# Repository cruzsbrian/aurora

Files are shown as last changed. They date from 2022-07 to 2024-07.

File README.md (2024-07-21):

# Aurora
Aurora is an addressable LED controller with a graphical interface, audio input, and patterns programmed on an SD card.
It controls up to 8 WS2811-style LED strips in parallel.
A microphone and audio jack can be used for music visualization.
LED patterns are programmed in Lua and can be modified without rebooting by replacing the SD card.

[Interactive PCB BOM viewer](https://htmlpreview.github.io/?https://github.com/cruzsbrian/aurora/blob/main/aurora_hw/bom/ibom.html)

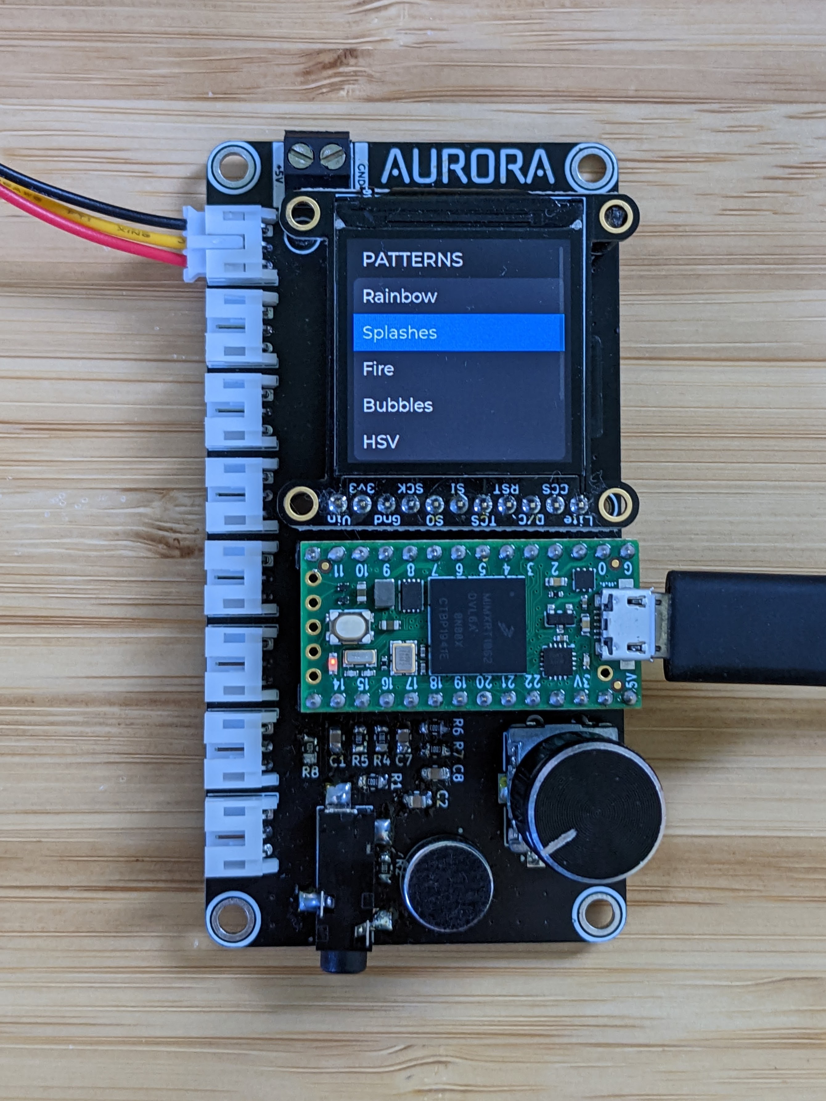
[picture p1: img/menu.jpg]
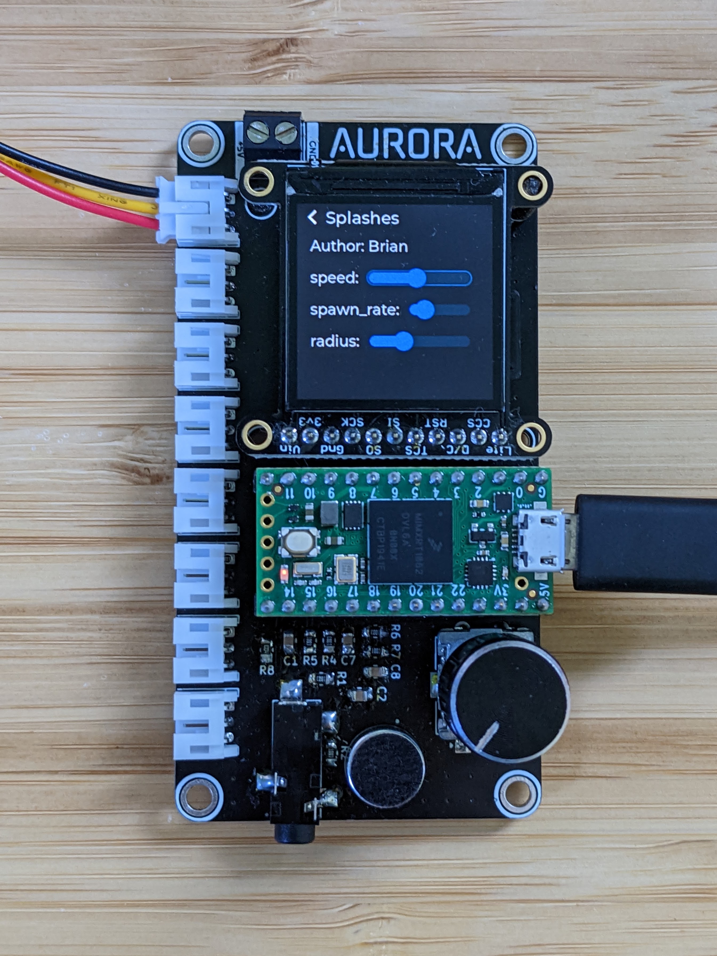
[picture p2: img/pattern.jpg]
|  |  |
| --- | --- |

## Configuring LED Strips

`aurora_sw/src/lights.h` contains configuration for the number of strips and their lengths and directions.

`N_STRIPS` is the total number of strips (starting from the top connector).  
`LEDS_PER_STRIP` the maximum number of LEDs on a single strip.  
`N_LEDS` is the total number of LEDs (the sum of all the strip lengths, less than or equal to `N_STRIPS * LEDS_PER_STRIP`).  
`n_leds[N_STRIPS]` is an array of the strip lengths.  
`led_dirs[N_STRIPS]` is an array of the strip directions.
1 indicates the strip should start from its first LED, -1 indicates it should start from its last LED.

## Writing Patterns

When an SD card is inserted, Aurora interprets each Lua file in its root directory as a pattern.
The title of a pattern is its filename, minus the `.lua` extension.

Every pattern must define an `update()` function to display one frame of its animation, which will be called at 50 Hz.

Patterns can set LED colors with the `setRGB(i, r, g, b)` and `setHSV(i, h, s, v)` functions, where `i` is the index of the LED (starting at 1 to follow the Lua convention) and the other parameters specify the color (all values ranging from 0 to 1).
Patterns can also inspect the current color of an LED with `getRGB(i)`, which returns the red, green, and blue values from 0 to 1.

Calling `print(arg1, arg2, ...)` from Lua prints to the serial console.

A pattern can specify any number of "parameters" for itself, which appear as sliders in the UI, with `add_param(name, min, max, step, default)`, where `name` is a string, and `max`, `min`, `step`, `default` are floating point numbers.
The parameter will then be available as a global variable in the Lua environment for that pattern (so `name` must be a valid Lua variable name).

Here is an example pattern which displays a rainbow repeated a configurable number of times (set by `cycles`) moving at a configurable speed:
```Lua
add_param("speed", 0, 1, 0.05, 0.15)
add_param("cycles", 1, 10, 1, 1)

start = 0

function update()
    for i=1,N_LEDS do
        -- Calculate hue based on LED position, rainbow start position, and number of cycles.
        h = ((i - start) * cycles / N_LEDS) % 1
        
        -- Set LED to calculated hue, full saturation, 25% brightness.
        setHSV(i, h, 1, 0.25)
    end

    start = start + speed
end
```

# Compile / Upload:
## Site Customization: : 
Although you can run the Aurora firmware as-is, you will probably want to go in and customize the LED settings to match the specific layout of your installation. This customization is done in the aurora_sw/src/lights.h file as follows. Examples are included for a few different possible configurations. 

Important Parameters:
- *LED_BRIGHTNESS:* How bright should "full" brightness be. Higher values will provide more light and color depth, but will also increase current use and may introduce color aberration on longer strips when many LEDs are lit. A default value of 100 will work in most environments. 
- *N_STRIPS:* How many different led strips there are. In this context a strip is defined as a group of LEDs which all share one signal line. 
- *LEDS_PER_STRIP:* The maximum number of LEDs on any one strip.
- *N_LEDS:* The total number of LEDs, this should be the sum of "n_leds".
- *n_leds:* How many LEDs there are in each strip. For custom installations it may be nessary to count, or to upload debug patterns to precisely determine this number. Incorrect values with result in lost pixels. 
- *led_dirs:* Which direction each strip runs relative to the direction of signal. You can pick either clockwise or counter-clockwise as the logic direction, but it must remain consistent to prevent animation jumps. Clockwise is a good default. 
## Windows Setup: 
Write-up Coming Soon!

## Linux Setup: 
The Linux install instructions assume that you have Version 1.x.x of the Arduino IDE installed, along with teensyduino which is used to upload code to the Teensy. Instructions for installing teensyduino (and links to arduino installers) can be found here: https://www.pjrc.com/teensy/teensyduino.html. It is definitely worth checking that your install works by uploading one of the teensy example scripts before proceeding. 

Setting up the build environment is pretty straightforward, but it does involve mucking around in the arduino libraries folder. If you have any questions definitely feel free to reach out. 

Using the arduino IDE Install: 
(Sketch -> Include Library -> Manage Libraries...)
 - SD
 - TFT_eSPI
 - lvgl
 - arduinoFFT (for debugging, optional)
 
 Navigate to your a libraries folder (likely /home/[name]/Arduino/libraries) and clone the [arduinoLua](https://github.com/blackketter/LuaArduino) repo. 
 
 Now copy the lv_conf.h file from /aurora_sw/src/ to the top level of your Arduino libraries folder. This configures the GUI generator.
 
 In your arduino libraries folder, replace TFT_eSPI/User_Setup.h with the User_Setup.h file provided in aurora_sw/src/. This configures the pins and dimensions of the display itself. 
 
 Rename /aurora_sw/src/main.cpp to /aurora_sw/src/main.ino so that it will be detected by the Arduino IDE. 
 
 You can now open src.ino with the Arduino IDE. 
 
 Before uploading you will need to set the optimizer (tools -> optimize) to "Smallest Code".
 
 You are now ready to upload!
 
 # Hardware Setup / Assembly: 
 
 ## Tips:
 - The MAX9814 is the board's most fiddly component, so if you are going to use the microphone, it pays to solder that first.
 - The fft_debug script can be used to check if the audio components are
   correctly installed. To use it install the script, and then play tones from
   your phone. The tones played and the tones reported on the serial monitor 
   should match to within 1hz or so over 200hz - 4000hz.

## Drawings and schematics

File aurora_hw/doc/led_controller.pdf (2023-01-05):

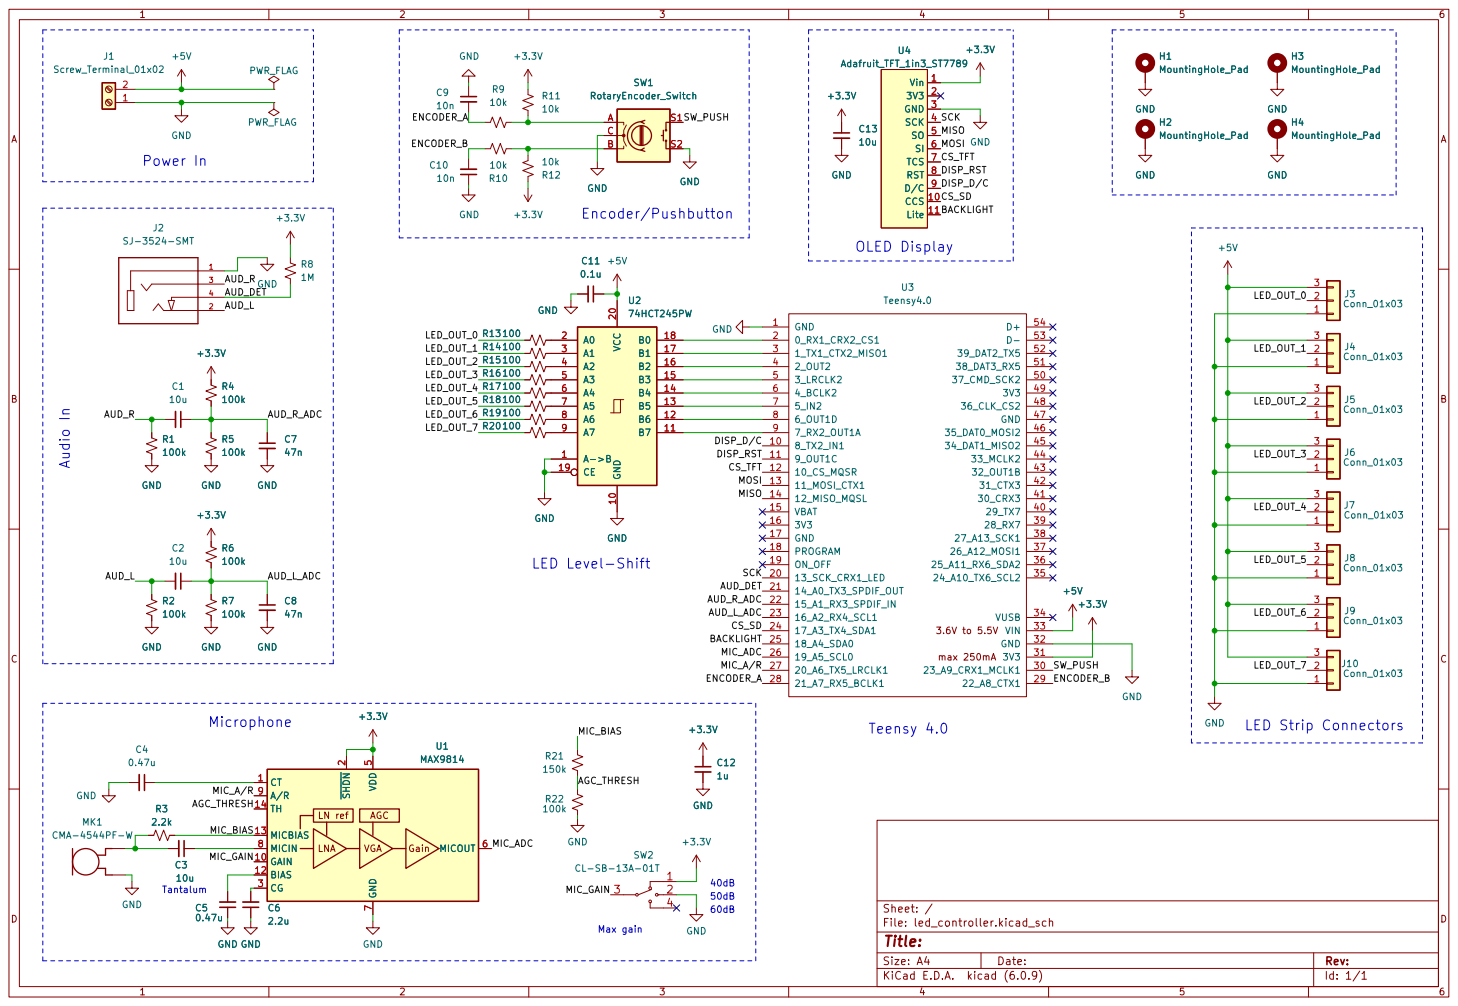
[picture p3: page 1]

BACKLIGHT MISO MOSI Power In Audio In

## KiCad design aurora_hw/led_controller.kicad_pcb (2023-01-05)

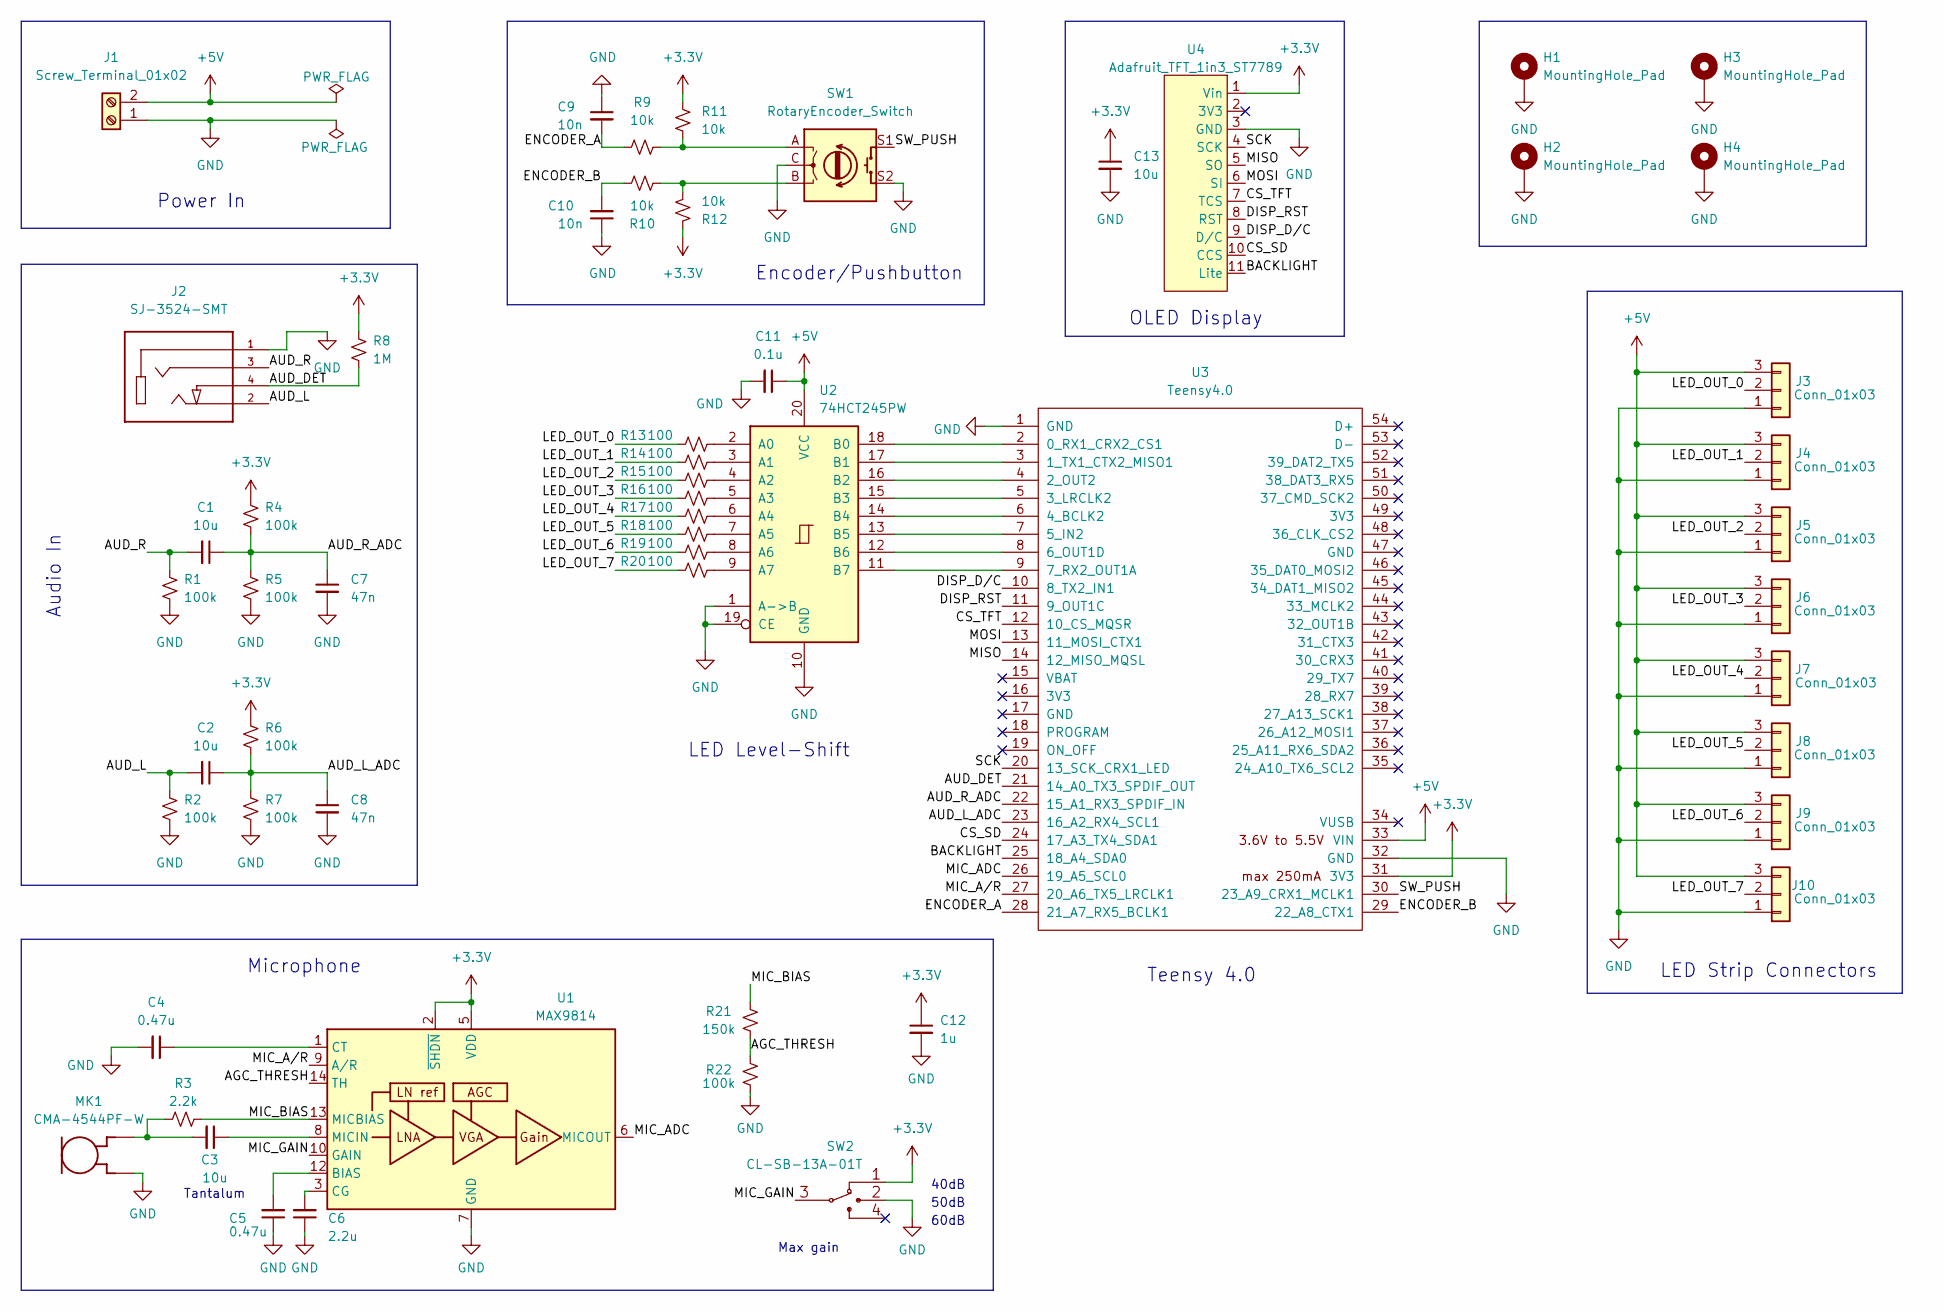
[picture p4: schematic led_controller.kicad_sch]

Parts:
C1, C2, C13: 10u; C_0805_2012Metric_Pad1.18x1.45mm_HandSolder
C3: 10u; C_0805_2012Metric_Pad1.18x1.45mm_HandSolder; LCSC Part Number C49678
C4, C5: 0.47u; C_0805_2012Metric_Pad1.18x1.45mm_HandSolder; LCSC Part Number C13967
C6: 2.2u; C_0805_2012Metric_Pad1.18x1.45mm_HandSolder; LCSC Part Number C49217
C7, C8: 47n; C_0805_2012Metric_Pad1.18x1.45mm_HandSolder
C9, C10: 10n; C_0805_2012Metric_Pad1.18x1.45mm_HandSolder; LCSC Part Number C1710
C11: 0.1u; C_0805_2012Metric_Pad1.18x1.45mm_HandSolder; LCSC Part Number C49678
C12: 1u; C_0805_2012Metric_Pad1.18x1.45mm_HandSolder; LCSC Part Number C49217
H1, H2, H3, H4: MountingHole_Pad; MountingHole_3.2mm_M3_ISO14580_Pad; LCSC Part Number N/A
J1: Screw_Terminal_01x02; TerminalBlock_Molex_393570002_1x02_P3.50mm_Horizontal; LCSC Part Number N/A
J2: SJ-3524-SMT; CUI_SJ-3524-SMT; LCSC Part Number N/A
J3, J4, J5, J6, J7, J8, J9, J10: Conn_01x03; JST_PH_S3B-PH-K_1x03_P2.00mm_Horizontal; LCSC Part Number N/A
MK1: CMA-4544PF-W; MIC_CMA-4544PF-W; LCSC Part Number N/A
R1, R2, R4, R5, R6, R7, R22: 100k; R_0805_2012Metric_Pad1.20x1.40mm_HandSolder; LCSC Part Number C149504
R3: 2.2k; R_0805_2012Metric_Pad1.20x1.40mm_HandSolder; LCSC Part Number C17520
R8: 1M; R_0805_2012Metric_Pad1.20x1.40mm_HandSolder
R9, R10, R11, R12: 10k; R_0805_2012Metric_Pad1.20x1.40mm_HandSolder; LCSC Part Number C17414
R13, R14, R15, R16, R17, R18, R19, R20: 100; R_0805_2012Metric_Pad1.20x1.40mm_HandSolder; LCSC Part Number C17408
R21: 150k; R_0805_2012Metric_Pad1.20x1.40mm_HandSolder; LCSC Part Number C17470
SW1: RotaryEncoder_Switch; RotaryEncoder_Alps_EC11E-Switch_Vertical_H20mm; LCSC Part Number N/A
SW2: CL-SB-13A-01T
U1: MAX9814; TDFN-14-1EP_3x3mm_P0.4mm_EP1.78x2.35mm_ThermalVias; LCSC Part Number C41714
U2: 74HCT245PW; TSSOP-20_4.4x6.5mm_P0.65mm; LCSC Part Number C5980
U3: Teensy4.0; Teensy40; LCSC Part Number N/A
U4: Adafruit_TFT_1in3_ST7789; LCSC Part Number N/A

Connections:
+3V3: C12.1, C13.1, R4.1, R6.1, R8.1, R11.1, R12.1, SW2.1, U1.2 (~SHDN), U1.5 (VDD), U3.31 (3V3), U4.1 (Vin)
+5V: C11.1, J1.2, J3.3, J4.3, J5.3, J6.3, J7.3, J8.3, J9.3, J10.3, U2.20 (VCC), U3.33 (VIN)
/AGC_THRESH: R21.1, R22.2, U1.14 (TH)
/AUD_DET: J2.4, R8.2, U3.21 (14_A0_TX3_SPDIF_OUT)
/AUD_L: C2.2, J2.2, R2.1
/AUD_L_ADC: C2.1, C8.1, R6.2, R7.1, U3.23 (16_A2_RX4_SCL1)
/AUD_R: C1.2, J2.3, R1.1
/AUD_R_ADC: C1.1, C7.1, R4.2, R5.1, U3.22 (15_A1_RX3_SPDIF_IN)
/BACKLIGHT: U3.25 (18_A4_SDA0), U4.11 (Lite)
/CS_SD: U3.24 (17_A3_TX4_SDA1), U4.10 (CCS)
/CS_TFT: U3.12 (10_CS_MQSR), U4.7 (TCS)
/DISP_D/C: U3.10 (8_TX2_IN1), U4.9 (D/C)
/DISP_RST: U3.11 (9_OUT1C), U4.8 (RST)
/ENCODER_A: C9.2, R9.2, U3.28 (21_A7_RX5_BCLK1)
/ENCODER_B: C10.2, R10.1, U3.29 (22_A8_CTX1)
/LED_OUT_0: J3.2, R13.1
/LED_OUT_1: J4.2, R14.1
/LED_OUT_2: J5.2, R15.1
/LED_OUT_3: J6.2, R16.1
/LED_OUT_4: J7.2, R17.1
/LED_OUT_5: J8.2, R18.1
/LED_OUT_6: J9.2, R19.1
/LED_OUT_7: J10.2, R20.1
/MIC_ADC: U1.6 (MICOUT), U3.26 (19_A5_SCL0)
/MIC_A/R: U1.9 (A/R), U3.27 (20_A6_TX5_LRCLK1)
/MIC_BIAS: R3.2, R21.2, U1.13 (MICBIAS)
/MIC_GAIN: SW2.3, U1.10 (GAIN)
/MISO: U3.14 (12_MISO_MQSL), U4.5 (SO)
/MOSI: U3.13 (11_MOSI_CTX1), U4.6 (SI)
/SCK: U3.20 (13_SCK_CRX1_LED), U4.4 (SCK)
/SW_PUSH: SW1.S1, U3.30 (23_A9_CRX1_MCLK1)
GND: C4.2, C5.1, C6.1, C7.2, C8.2, C9.1, C10.1, C11.2, C12.2, C13.2, H1.1, H2.1, H3.1, H4.1, J1.1, J2.1, J3.1, J4.1, J5.1, J6.1, J7.1, J8.1, J9.1, J10.1, MK1.2, R1.2, R2.2, R5.2, R7.2, R22.1, SW1.C, SW1.S2, SW2.2, U1.4 (GND), U1.7 (GND), U1.11 (GND), U1.15 (GND), U2.1 (A->B), U2.10 (GND), U2.19 (CE), U3.1 (GND), U3.32 (GND), U4.3 (GND)
unnamed: C3.1, U1.8 (MICIN)
unnamed: C3.2, MK1.1, R3.1
unnamed: C4.1, U1.1 (CT)
unnamed: C5.2, U1.12 (BIAS)
unnamed: C6.2, U1.3 (CG)
unnamed: R10.2, R12.2, SW1.B
unnamed: R9.1, R11.2, SW1.A
unnamed: R13.2, U2.2 (A0)
unnamed: R14.2, U2.3 (A1)
unnamed: R15.2, U2.4 (A2)
unnamed: R16.2, U2.5 (A3)
unnamed: R17.2, U2.6 (A4)
unnamed: R18.2, U2.7 (A5)
unnamed: R19.2, U2.8 (A6)
unnamed: R20.2, U2.9 (A7)
unnamed: U2.11 (B7), U3.9 (7_RX2_OUT1A)
unnamed: U2.12 (B6), U3.8 (6_OUT1D)
unnamed: U2.13 (B5), U3.7 (5_IN2)
unnamed: U2.14 (B4), U3.6 (4_BCLK2)
unnamed: U2.15 (B3), U3.5 (3_LRCLK2)
unnamed: U2.16 (B2), U3.4 (2_OUT2)
unnamed: U2.17 (B1), U3.3 (1_TX1_CTX2_MISO1)
unnamed: U2.18 (B0), U3.2 (0_RX1_CRX2_CS1)

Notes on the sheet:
50dB
Power In
Teensy 4.0
Encoder/Pushbutton
Max gain
Tantalum
60dB
Microphone
Audio In
40dB
LED Level-Shift
LED Strip Connectors
OLED Display

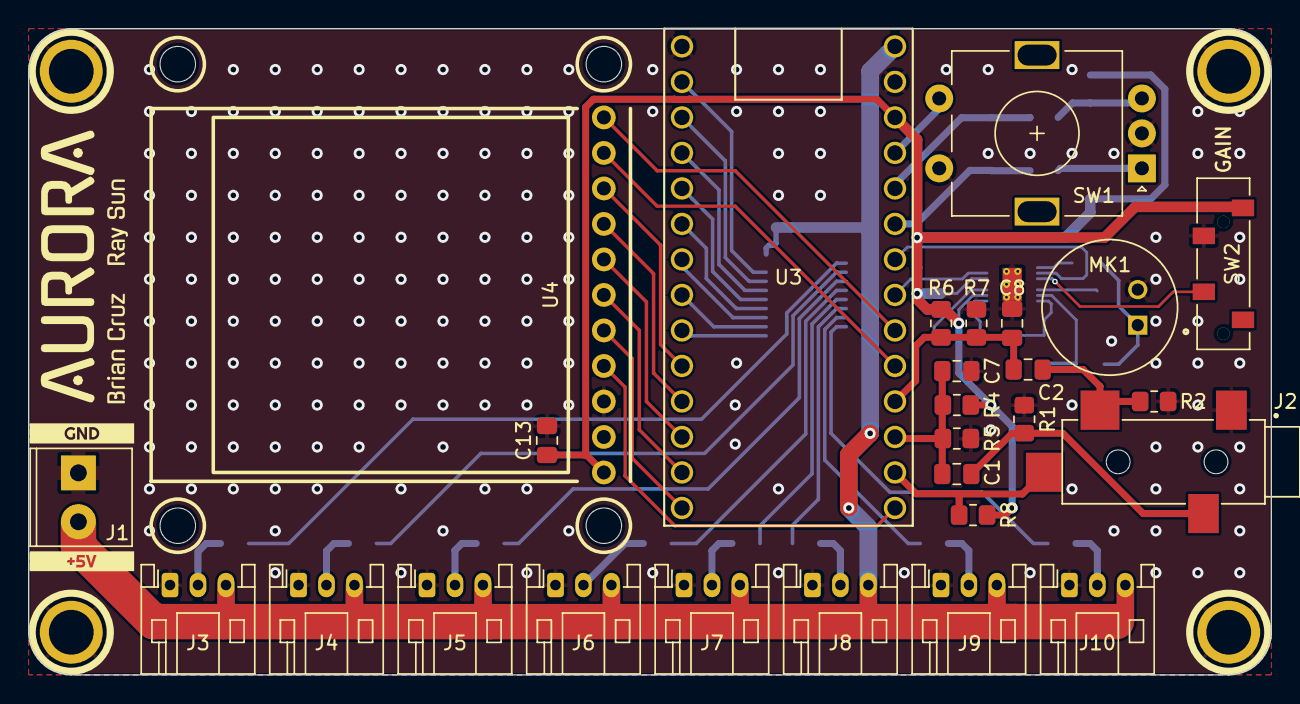
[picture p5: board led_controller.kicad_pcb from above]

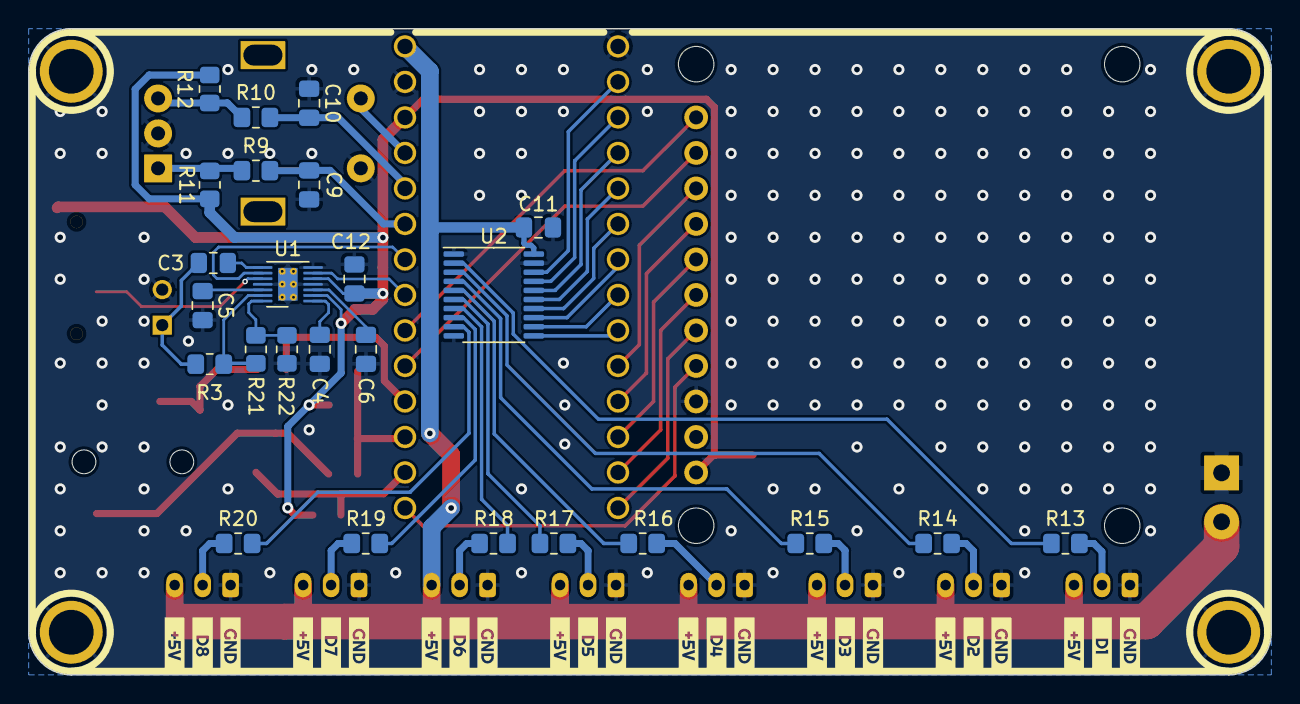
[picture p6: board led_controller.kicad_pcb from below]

Board: 2 copper layers, 88.9 x 46.2 mm, 84 parts (49 on the bottom side), 55 nets.

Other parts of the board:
kibuzzard-62AD5F1D: G***; kibuzzard-62AD5F1D
kibuzzard-62AD5F34: G***; kibuzzard-62AD5F34
kibuzzard-62AD6AEC, kibuzzard-62AD6AEC1, kibuzzard-62AD6AEC2, kibuzzard-62AD6AEC3, kibuzzard-62AD6AEC4, kibuzzard-62AD6AEC5, kibuzzard-62AD6AEC6, kibuzzard-62AD6AEC7: G***; kibuzzard-62AD6AEC
kibuzzard-62AD6B1, kibuzzard-62AD6B2, kibuzzard-62AD6B3, kibuzzard-62AD6B4, kibuzzard-62AD6B04, kibuzzard-62AD6B5, kibuzzard-62AD6B6, kibuzzard-62AD6B7: G***; kibuzzard-62AD6B04
kibuzzard-62AD6B13: G***; kibuzzard-62AD6B13
kibuzzard-62AD6BA8: G***; kibuzzard-62AD6BA8
kibuzzard-62AD6BC2: G***; kibuzzard-62AD6BC2
kibuzzard-62AD6C4C: G***; kibuzzard-62AD6C4C
kibuzzard-62AD6C16: G***; kibuzzard-62AD6C16
kibuzzard-62AD6C27: G***; kibuzzard-62AD6C27
kibuzzard-62AD6C38: G***; kibuzzard-62AD6C38
kibuzzard-62AD6C62: G***; kibuzzard-62AD6C62
kibuzzard-62AD66A7: G***; kibuzzard-62AD66A7
kibuzzard-62AD66B6: G***; kibuzzard-62AD66B6

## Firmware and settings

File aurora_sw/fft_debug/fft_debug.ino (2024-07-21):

/*
  Audio Debug Script: When loaded onto aurora, this script will publish the 
  loudest frequency detected on both of the audio channels. The gain switch
  on the microphone should be switched fully right before use. 

  Previously: 
	Example of use of the FFT libray to compute FFT for several signals over a range of frequencies.
        The exponent is calculated once before the excecution since it is a constant.
        This saves resources during the excecution of the sketch and reduces the compiled size.
        The sketch shows the time that the computing is taking.
        Copyright (C) 2014 Enrique Condes

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
*/

#include "arduinoFFT.h"

arduinoFFT FFT = arduinoFFT(); /* Create FFT object */
/*
These values can be changed in order to evaluate the functions
*/

const uint16_t samples = 4096;
uint8_t exponent;

#define PIN_JACK 16
#define PIN_MIC 19
#define TIME_DELAY 100 // in milliseconds.

/*
These are the input and output vectors
Input vectors receive computed results from FFT
*/
double vReal[samples];
double vImag[samples];

unsigned long time;

#define SCL_INDEX 0x00
#define SCL_TIME 0x01
#define SCL_FREQUENCY 0x02
#define SCL_PLOT 0x03

void setup()
{
  Serial.begin(115200);
  while(!Serial);
  Serial.println("Ready");
  exponent = FFT.Exponent(samples);
  Serial.println("Jack Frequency\tMic Frequency");
  Serial.println("=======================================\n");
}

void loop()
{
  /* Build raw data for the aux-jack*/
  double tic = micros();
  for (uint16_t i = 0; i < samples; i++)
  {
    vReal[i] = int8_t(analogRead(PIN_JACK));
    vImag[i] = 0; //Reset the imaginary values vector for each new frequency
    delayMicroseconds(TIME_DELAY);
  }
  double toc = micros();
  int sampling = int(samples / ((toc - tic) / 1000000));
  

  time=millis();
  FFT.Windowing(vReal, samples, FFT_WIN_TYP_HAMMING, FFT_FORWARD);	/* Weigh data */

  FFT.Compute(vReal, vImag, samples, exponent, FFT_FORWARD); /* Compute FFT */

  FFT.ComplexToMagnitude(vReal, vImag, samples); /* Compute magnitudes */

  double x_jack = FFT.MajorPeak(vReal, samples, sampling);

  //++++++++++++++++++++++++++++++++++++//

  /* Collect data for speaker */
  tic = micros();
  for (uint16_t i = 0; i < samples; i++)
  {
    vReal[i] = int8_t(analogRead(PIN_MIC));
    vImag[i] = 0; //Reset the imaginary values vector for each new frequency
    delayMicroseconds(TIME_DELAY);
  }
  toc = micros();
  sampling = int(samples / ((toc - tic) / 1000000));
  /*Serial.println("Data:");
  PrintVector(vReal, samples, SCL_TIME);*/
  FFT.Windowing(vReal, samples, FFT_WIN_TYP_HAMMING, FFT_FORWARD);  /* Weigh data */

  FFT.Compute(vReal, vImag, samples, exponent, FFT_FORWARD); /* Compute FFT */

  FFT.ComplexToMagnitude(vReal, vImag, samples); /* Compute magnitudes */

  double x_speaker = FFT.MajorPeak(vReal, samples, sampling);
  
  Serial.print(x_jack, 4);
  Serial.print("\t\t");
  Serial.print(x_speaker, 4);
  Serial.print("\t\t");
  Serial.println(" ");
}

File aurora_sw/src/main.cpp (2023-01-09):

#include <vector>
#include <string>

#include <SD.h>
#include <Metro.h>

#include "ui.h"
#include "pattern.h"
#include "lights.h"


using namespace std;


#define SD_CS 17


bool card_inserted = false;

vector<Pattern> patterns;
unsigned int current_pattern_idx = 0;
long last_pattern_update = 0;

const long pattern_update_interval = 20; // ms

const long fps_update_millis = 1000;
long last_fps_update_time = 0;
long frames = 0;


vector<Pattern> get_patterns_from_sd(File dir) {
    vector<Pattern> patterns;

    // Loop through all files.
    while (File entry = dir.openNextFile()) {
        if (!entry.isDirectory()) {
            string filename = entry.name();
            Serial.println(filename.c_str());

            // If it has a lua extension, add it to the list.
            if (filename.substr(filename.length() - 4) == ".lua") {
                string name = filename.substr(0, filename.length() - 4);
                patterns.push_back(Pattern(patterns.size(), name, filename));
            }
        }
        entry.close();
    }

    return patterns;
}


void load_pattern(unsigned int idx) {
    if (idx >= patterns.size()) return;

    Serial.print(F("Loading pattern "));
    Serial.println(patterns[idx].name.c_str());

    // Unload current pattern.
    patterns[current_pattern_idx].unload();

    lights::blank();

    // Load new pattern.
    patterns[idx].load();
    current_pattern_idx = idx;
}



void setup() {
    Serial.begin(115200);
    Serial.println("Starting up");

    ui::init();
    lights::init();

    // Try to initialize the SD card.
    // If inserted, load the pattern list. If not, show the card removed page.
    Serial.print(F("Initializing SD card..."));
    if (SD.begin(SD_CS)) {
        Serial.println(F("OK!"));
        card_inserted = true;
        patterns = get_patterns_from_sd(SD.open("/"));
        ui::populate_root_page(patterns);

        load_pattern(current_pattern_idx);
    } else {
        Serial.println(F("failed!"));
        ui::card_removed();
    }
}


void loop() {
    // Detect SD card insertion/removal.
    // If inserted, load the pattern list. If not, show the card removed page.
    if (SD.mediaPresent() && !card_inserted) {
        card_inserted = true;
        patterns = get_patterns_from_sd(SD.open("/"));
        ui::populate_root_page(patterns);

        load_pattern(current_pattern_idx);
    } else if (!SD.mediaPresent() && card_inserted) {
        card_inserted = false;
        ui::card_removed();

        patterns[current_pattern_idx].unload();
        current_pattern_idx = 0;
        ui::selected_pattern = 0;

        lights::blank();
    }

    ui::update();

    if (ui::selected_pattern != current_pattern_idx) {
        load_pattern(ui::selected_pattern);
    }

    // If pattern_update_interval has passed, update the current pattern.
    // Also update the FPS counter every fps_update_millis.
    if (millis() - last_pattern_update >= pattern_update_interval && current_pattern_idx < patterns.size()) {
        last_pattern_update = millis();

        // long start = millis();
        patterns[current_pattern_idx].update();
        lights::show();
        // Serial.print("Pattern update took: "); Serial.print(millis() - start); Serial.println("ms");

        if (millis() - last_fps_update_time >= fps_update_millis) {
            Serial.print("FPS: "); Serial.println(1000.0 * (double) frames / (double) (millis() - last_fps_update_time));
            last_fps_update_time = millis();
            frames = 0;
        }

        frames++;
    }

    // Check to see if serial data is available. If so, write it to the SD card for the current pattern and reload the pattern.
    if (Serial.available()) {
        // Read first line to see what the command is.
        string command = Serial.readStringUntil('\n').c_str();

        // Read the rest of the data
        string data;
        while (Serial.available()) {
            data += (char) Serial.read();
        }

        Serial.println("Received on serial: ");
        Serial.println(command.c_str());
        Serial.println(data.c_str());

        if (command == "LOAD" || command == "SAVE") {
            lights::blank();
            patterns[current_pattern_idx].upload_code(data.c_str());
        }

        if (command == "SAVE") {
            patterns[current_pattern_idx].save_code(data.c_str());
        }
    }

    delay(1);
}

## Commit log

2022-06-16 Start layout, choose display
    [led_controller.kicad_pcb, led_controller.kicad_sch]
2022-06-17 Place passives, route all except power
    [led_controller.kicad_pcb, led_controller.kicad_sch]
2022-06-18 Rearrange screen and power, add 3D models
    [led_controller.kicad_pcb, led_controller.kicad_sch]
2022-06-18 Finish routing, add text, via grid, round tracks
    [led_controller-rounded.kicad_pcb, led_controller.kicad_sch]
2022-06-18 Add origin markers, clean stackup, add some art
    [led_controller.kicad_pcb]
2022-06-18 Update Teensy model sockets
    [led_controller.kicad_pcb]
2022-06-19 Fix audio jack pinout and route jack insertion pin
    [led_controller.kicad_pcb, led_controller.kicad_sch]
2022-06-19 Enter pads at right angles for aesthetics
    [led_controller.kicad_pcb]
2022-06-20 Rearrange some analog pins, tweak routing
    [led_controller-rounded.kicad_pcb, led_controller.kicad_pcb, led_controller.kicad_sch]
2022-06-20 Fix some clearance issues
    [led_controller-rounded.kicad_pcb]
2022-06-21 some more tweaks
    [led_controller-rounded.kicad_pcb, led_controller.kicad_pcb, led_controller.kicad_sch]
2022-06-21 Fix DRC clearance violations
    [led_controller-rounded.kicad_pcb]
2022-06-21 Generate position file
    [led_controller-rounded-bottom-pos.csv]
2022-06-22 Edit symbol fields for PCB assembly
    [led_controller.kicad_sch]
2022-06-25 Switch to molex nano-fit connectors
    [led_controller-rounded.kicad_pcb, led_controller.kicad_pcb]
2022-06-26 Revert "Switch to molex nano-fit connectors"
    This reverts commit 9b38a182e228fa806dde65dc415f981188c8a403.
    [led_controller-rounded.kicad_pcb, led_controller.kicad_pcb]
2022-06-27 verified by Brian, create gerbers
    [led_controller-rounded-B_Cu.gbl, led_controller-rounded-B_Mask.gbs, led_controller-rounded-B_Paste.gbp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]
2022-07-25 Clean up hw files, move to subfolder
    [led_controller-rounded-B_Cu.gbl, led_controller-rounded-B_Mask.gbs, led_controller-rounded-B_Paste.gbp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]
2022-09-10 writing LEDs w/ OctoWS2811, HSV and print for lua
2022-09-12 Use interrupts for patterns instead of Metro
2022-09-14 replace lua leds array with setRGB, setHSV, getRGB
    [lights.h, main.cpp, pattern.cpp]
2022-09-14 Replace interrupt with timer for pattern update
    [main.cpp]
2022-09-14 Make linguist ignore the HTML BOM
2022-09-20 Change BOM viewer link, add lib to linguist-vendored
2022-11-22 Add switch for changing A/R ratio, lengthen DFN pads
    [led_controller.kicad_pcb, led_controller.kicad_sch]
2022-11-22 Shrink mic amp GND pad to increase clearance
    [led_controller.kicad_pcb]
2023-01-05 Hardware v2
    [led_controller-B_Cu.gbl, led_controller-B_Mask.gbs, led_controller-B_Silkscreen.gbo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]
2023-01-05 Support different strip lengths, fix indexing
    [lights.h, pattern.cpp]
2023-01-05 Add PDF of schematic
2023-01-07 Fix strip config bug, move all config to lights.h
    [lights.h]
2023-01-09 Blank LEDs when receiving pattern via serial
2023-01-09 Fix scrolling for menu subpages
    [ui.cpp]
2023-02-05 better solution for arduino IDE compatability.

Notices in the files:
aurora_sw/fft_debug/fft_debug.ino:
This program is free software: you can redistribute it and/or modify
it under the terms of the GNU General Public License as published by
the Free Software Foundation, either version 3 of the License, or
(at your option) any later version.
